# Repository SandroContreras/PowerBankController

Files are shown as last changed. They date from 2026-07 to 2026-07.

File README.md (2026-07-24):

# Power Bank Controller
Custom 8-cell lithium-ion power bank with embedded monitoring via MicroPython and OLED display.
<br><br>
**Project Status: PCB revision 1 ordered; assembly and electrical validation pending.**
<br><br>
## Overview
This project is a custom 8-cell (8×18650) lithium-ion power bank controller designed to explore
high-current PCB design, USB-C power delivery behavior, and real-world manufacturing constraints.
The board was designed in KiCad and fabricated as a 2-oz copper PCB.

<br>

## Features
- 8× LG MJ1 cells in parallel (~100.8 Wh)
- USB-C power output via IP5310 power-bank SoC
- 2 oz copper PCB for high-current paths
- Per-cell polyfuse protection
- Raspberry Pi Pico for battery monitoring
- Designed for serviceable, replaceable cells

<br>

## How It's Made
**Tech Used:** MicroPython, Raspberry Pi Pico, SSD1306 OLED Display
<br>
Eight 18650 batteries are wired in parallel to a boost converter charging module. The charging module powers the Pico Board and the OLED Display. To achieve battery health displays a voltage divider is used to safely bring down the voltage towards an ADC pin. The display is programmed to display the reported battery health percentage for the user. 

<br><br>

## Design Decisions & Tradeoffs
- Used 18650 holders instead of spot-welded packs to improve safety and serviceability.
- Selected 2 oz copper to reduce voltage drop and thermal stress in high-current paths.
- Chose IP5310 to simplify power-bank control while accepting uncertainty around USB-PD behavior.
- Accepted larger PCB size to prioritize current handling and mechanical robustness.

<br><br>

## Future Work
- Assemble and electrically validate the V1 prototype.
- Verify USB-C charging, 5 V boost output, OLED operation, and Raspberry Pi Pico functionality.
- Perform electrical and thermal testing under sustained load.
- Measure boost converter efficiency and battery runtime with the final 8-cell LG MJ1 battery pack.
- Design and fabricate a custom enclosure suitable for camping use.
- Evaluate the need for a V2 PCB revision based on functional and thermal test results.

<br><br>

## Data Flow

<p align="center">
    Data Flowchart
</p>
<p align="center"><em>Data flow from ADC voltage reading to OLED UI output.</em></p>

<br><br><br><br><br><br><br><br>

## Circuit Diagram

<p align = "center">
    Portable Power Bank - High-Level Circuit Diagram
</p>
<p align = "center"><em>High-Level Circuit Diagram.</em></p>

<p align = "center">
    Portable Power Bank - PCB Circuit Diagram
</p>
<p align = "center"><em>PCB Circuit Diagram.</em></p> 

<br><br><br>

## Lessons Learned
This project was my first complete custom PCB, from schematic capture through PCB layout, manufacturing, and assembly. Along the way I learned several practical engineering lessons:
    - The importance of verifying component footprints, pinouts, and manufacturer datasheets before ordering parts.
    - How PCB stack-up, copper pours, via placement, and trace widths affect power distribution and thermal performance.
    - The value of building a complete BOM and selecting components based on both electrical requirements and long-term serviceability.
    - That designing a functional hardware system often requires multiple design reviews and may require more than one PCB revision before reaching a mature design.

<br><br><br>

## Included Modules
- 'bisect.py' - From the Python Standard Library (CPython 3.13)
- Source: https://github.com/python/cpython
- License: Python Software Foundation License (PSF)

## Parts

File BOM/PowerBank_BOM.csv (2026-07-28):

BOM Revision: | V1 Prototype |  | Last Updated: | July 28, 2026
Item | Quantity Required | Quantity Stocked | Supplier | Datasheet | Unit Cost | Cost Per Board
PCB Manufacturing: | 5 | 0 |  |  | $93.31 | $145.12
PCB Shipping: | 1 | N/A |  |  | $59.05
Raspberry Pi Pico | 1 | 1 | Pi Pico Purchase | Pi Pico | $4.00
22uF Capacitor | 6 | 8 | 22uF Cap Purchase Link | 22uF Cap Datasheet | $0.95
1nF Capacitor | 1 | 10 | 1nF Cap Purchase Link | 1nF Cap Datasheet | $0.17
10uF Capacitor | 2 | 10 | 10uF Cap Purchase Link | 10uF Cap Datasheet | $0.43
1uF Capacitor | 1 | 0 | 1uF Cap Purchase Link | 1uF Cap Datasheet | $0.35
5.6V Zener Diode | 1 | 10 | 5.6V Zener Diode Purchase Link | Zener Datasheet | $0.56
Polyfuse | 8 | 0 | Polyfuse 2 Amp Hold Link | Polyfuse Datasheet | $0.60
USB-C Receptacle | 1 | 2 | USB-C Purchase Link | USB-C Port Datasheet | $0.61
Cell Holders | 8 | 8 | Cell Holder Link | Cell Holder Datasheet | $5.99
SDD1306 Oled | 1 | 3 | SSD1306 5 Pack Purchase Link | SSD1306 Oled Datasheet | $14.98
4 Pin Header Connector | 1 | 15 | Pin Header Purchase Link | Pin Header Datasheet | $0.69
1UH Inductor | 1 | 0 | 1UH Inductor Purchase Link | 1UH Inductor Datasheet | $1.97
PMOS Gate | 2 | 10 | PMOS Purchase Link | PMOS Datasheet | $0.50
BJT Gate | 1 | 10 | BJT Purchase Link | BJT Datasheet | $0.16
47k Resistor | 1 | 2 | 47k Resistor Purchase Link | 47k Resistor Datasheet | $0.27
100k Resistor | 2 | 2 | 100k Resistor Purchase Link | 100k Resistor Datasheet | $0.10
100k NTC THERM Resistor | 1 | 2 | 100k NTC THERM Resistor Purchase Link | 100k NTC THERM Datasheet | $0.51
1k Resistor | 1 | 25 | 1k Resistor Purchase Link | 1k Resistor Datasheet | $0.10
0 ohm Resistor | 1 | 2 | 0 ohm Resistor Purchase Link | 0 ohm Resistor Datsheet | $0.10
82k Resistor | 1 | 2 | 82k Resistor Purchase Link | 82k Resistor Datasheet | $0.10
10k Resistor | 3 | 25 | 10k Resistor Purchase Link | 10k Resistor Datasheet | $0.10
2 ohm Resistor | 1 | 2 | 2 ohm Resistor Purchase Link | 2 ohm Resistor Datasheet | $0.10
Button (TL6340AF160Q) | 1 | 0 | TL6340AF160Q Purchase Link | Button Datasheet | $0.45
PMIC (IP5310) | 1 | 5 | IP5310 Purchase Link | IP5310 Datasheet | $0.71
18650’s (LG MJ1) | 8 | 0 | 18650 Purchase Link |  | $5.00

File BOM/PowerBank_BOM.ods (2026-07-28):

BOM Revision: | V1 Prototype |  | Last Updated: | July 28, 2026
Item | Quantity Required | Quantity Stocked | Supplier | Datasheet | Unit Cost | Cost Per Board
PCB Manufacturing: | 5 | 0 |  |  | $93.31 | $145.12
PCB Shipping: | 1 | N/A |  |  | $59.05
Raspberry Pi Pico | 1 | 1 | Pi Pico Purchase (https://www.mouser.com/en/ProductDetail/Raspberry-Pi/SC0915?qs=T%252BzbugeAwjgnLi4azxXVFA%3D%3D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) | Pi Pico (https://datasheets.raspberrypi.com/pico/pico-datasheet.pdf) | $4.00
22uF Capacitor | 6 | 8 | 22uF Cap Purchase Link (https://www.mouser.com/en/ProductDetail/TAIYO-YUDEN/MCASE31LBB7226MTNA01?qs=FmjOKN4Os85Enbuat7%252BsuA%3D%3D) | 22uF Cap Datasheet (https://www.mouser.com/datasheet/3/940/1/c_mlcc_C_e.pdf) | $0.95
1nF Capacitor | 1 | 10 | 1nF Cap Purchase Link (https://www.digikey.com/en/products/detail/kemet/C1206C102K5RAC7210/3317018?gclsrc=aw.ds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) | 1nF Cap Datasheet (https://yageogroup.com/content/datasheet/asset/file/KEM_C1002_X7R_SMD) | $0.17
10uF Capacitor | 2 | 10 | 10uF Cap Purchase Link (https://www.digikey.com/en/products/detail/tdk/C3216X7R0J106K085AB/3952027?gclsrc=aw.ds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) | 10uF Cap Datasheet (https://product.tdk.com/system/files/dam/doc/product/capacitor/ceramic/mlcc/catalog/mlcc_commercial_general_en.pdf) | $0.43
1uF Capacitor | 1 | 0 | 1uF Cap Purchase Link (https://www.mouser.com/en/ProductDetail/KYOCERA-AVX/KAF31NR71C105JU?qs=Jm2GQyTW%2FbiSKYrUbBGHAg%3D%3D) | 1uF Cap Datasheet (https://www.mouser.com/datasheet/3/5926/1/AutoMLCCKAF.pdf) | $0.35
5.6V Zener Diode | 1 | 10 | 5.6V Zener Diode Purchase Link (https://www.digikey.com/en/products/detail/onsemi/1SMA5919BT3G/918093) | Zener Datasheet (https://www.onsemi.com/pdf/datasheet/1sma5913bt3-d.pdf) | $0.56
Polyfuse | 8 | 0 | Polyfuse 2 Amp Hold Link (https://www.mouser.com/en/ProductDetail/Littelfuse/1812L200THPR?qs=CPcc0c%2Fon9GqZ5cxSO73Dg%3D%3D) | Polyfuse Datasheet (https://www.littelfuse.com/assetdocs/resettable-ptcs-1812l-datasheet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) | $0.60
USB-C Receptacle | 1 | 2 | USB-C Purchase Link (https://www.digikey.com/en/products/detail/gct/USB4125-GF-A/13547388?gclsrc=aw.ds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) | USB-C Port Datasheet (https://gct.co/files/specs/usb4125-spec.pdf) | $0.61
Cell Holders | 8 | 8 | Cell Holder Link (https://www.digikey.com/en/products/detail/keystone-electronics/1042/2745668?gclsrc=aw.ds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) | Cell Holder Datasheet (https://www.keyelco.com/userAssets/file/K75p29.pdf) | $5.99
SDD1306 Oled | 1 | 3 | SSD1306 5 Pack Purchase Link (https://www.amazon.com/Hosyond-Display-Self-Luminous-Compatible-Raspberry/dp/B09C5K91H7) | SSD1306 Oled Datasheet (https://cdn-shop.adafruit.com/datasheets/SSD1306.pdf) | $14.98
4 Pin Header Connector | 1 | 15 | Pin Header Purchase Link (https://www.digikey.com/en/products/detail/3m/961104-6404-AR/7104635?gclsrc=aw.ds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) | Pin Header Datasheet (https://mm.digikey.com/Volume0/opasdata/d220001/medias/docus/587/961_2.54mm_StraightSolderTail_DS.pdf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..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) | $0.69
1UH Inductor | 1 | 0 | 1UH Inductor Purchase Link (https://www.mouser.com/en/ProductDetail/Murata-Electronics/LQH66SN1R0M03L?qs=0erBW18kMP5jh%2Ffsz3MtpA%3D%3D) | 1UH Inductor Datasheet (https://www.mouser.com/datasheet/3/76/2/JELF243A_0047.pdf) | $1.97
PMOS Gate | 2 | 10 | PMOS Purchase Link (https://www.digikey.com/en/products/detail/vishay-siliconix/SI2371EDS-T1-BE3/16397468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..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) | PMOS Datasheet (https://www.vishay.com/docs/63924/si2371eds.pdf) | $0.50
BJT Gate | 1 | 10 | BJT Purchase Link (https://www.digikey.com/en/products/detail/onsemi/BCW68GLT1G/1476121) | BJT Datasheet (https://www.onsemi.com/pdf/datasheet/bcw68glt1-d.pdf) | $0.16
47k Resistor | 1 | 2 | 47k Resistor Purchase Link (https://www.digikey.com/en/products/detail/vishay-dale/CRCW120647K0JNEAHP/2222486) | 47k Resistor Datasheet (https://www.vishay.com/docs/20043/crcwhpe3.pdf) | $0.27
100k Resistor | 2 | 2 | 100k Resistor Purchase Link (https://www.digikey.com/en/products/detail/stackpole-electronics-inc/RMCF1206FT100K/1759689) | 100k Resistor Datasheet (https://www.seielect.com/catalog/SEI-RMCF_RMCP.pdf) | $0.10
100k NTC THERM Resistor | 1 | 2 | 100k NTC THERM Resistor Purchase Link (https://www.digikey.com/en/products/detail/kyocera-avx/NB20N50104JBA/1451942) | 100k NTC THERM Datasheet (https://datasheets.kyocera-avx.com/nb21-nb12-nb20.pdf) | $0.51
1k Resistor | 1 | 25 | 1k Resistor Purchase Link (https://www.digikey.com/en/products/detail/yageo/RC1206FR-131KL/13694125?gclsrc=aw.ds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) | 1k Resistor Datasheet (https://yageogroup.com/content/datasheet/asset/file/PYU-RC_GROUP_51_ROHS_L) | $0.10
0 ohm Resistor | 1 | 2 | 0 ohm Resistor Purchase Link (https://www.digikey.com/en/products/detail/yageo/RC1206FR-130RL/16982181?gclsrc=aw.ds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) | 0 ohm Resistor Datsheet (https://yageogroup.com/content/datasheet/asset/file/PYU-RC_GROUP_51_ROHS_L) | $0.10
82k Resistor | 1 | 2 | 82k Resistor Purchase Link (https://www.digikey.com/en/products/detail/yageo/RC0603FR-1082KL/14286523?gclsrc=aw.ds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) | 82k Resistor Datasheet (https://yageogroup.com/content/datasheet/asset/file/PYU-RC_GROUP_51_ROHS_L) | $0.10
10k Resistor | 3 | 25 | 10k Resistor Purchase Link (https://www.digikey.com/en/products/detail/yageo/RC1206FR-1010KL/13694170?gclsrc=aw.ds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) | 10k Resistor Datasheet (https://yageogroup.com/content/datasheet/asset/file/PYU-RC_GROUP_51_ROHS_L) | $0.10
2 ohm Resistor | 1 | 2 | 2 ohm Resistor Purchase Link (https://www.digikey.com/en/products/detail/yageo/RT1206DRE072RL/7708680) | 2 ohm Resistor Datasheet (https://yageogroup.com/content/datasheet/asset/file/PYU-RT_1-TO-0-01_ROHS_L) | $0.10
Button (TL6340AF160Q) | 1 | 0 | TL6340AF160Q Purchase Link (https://www.digikey.com/en/products/detail/e-switch/TL6340AF160Q/11684842) | Button Datasheet (https://configured-product-images.s3.amazonaws.com/Datasheets/TL6340.pdf) | $0.45
PMIC (IP5310) | 1 | 5 | IP5310 Purchase Link (https://www.lcsc.com/product-detail/Others_INJOINIC-IP5310_C191176.html) | IP5310 Datasheet (http://www.sztuofeng.com/upload/1586855153.pdf) | $0.71
18650’s (LG MJ1) | 8 | 0 | 18650 Purchase Link (https://18650battery.com/products/lg-mj1-18650-3500mah-10a-battery?variant=48703038456118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) |  | $5.00

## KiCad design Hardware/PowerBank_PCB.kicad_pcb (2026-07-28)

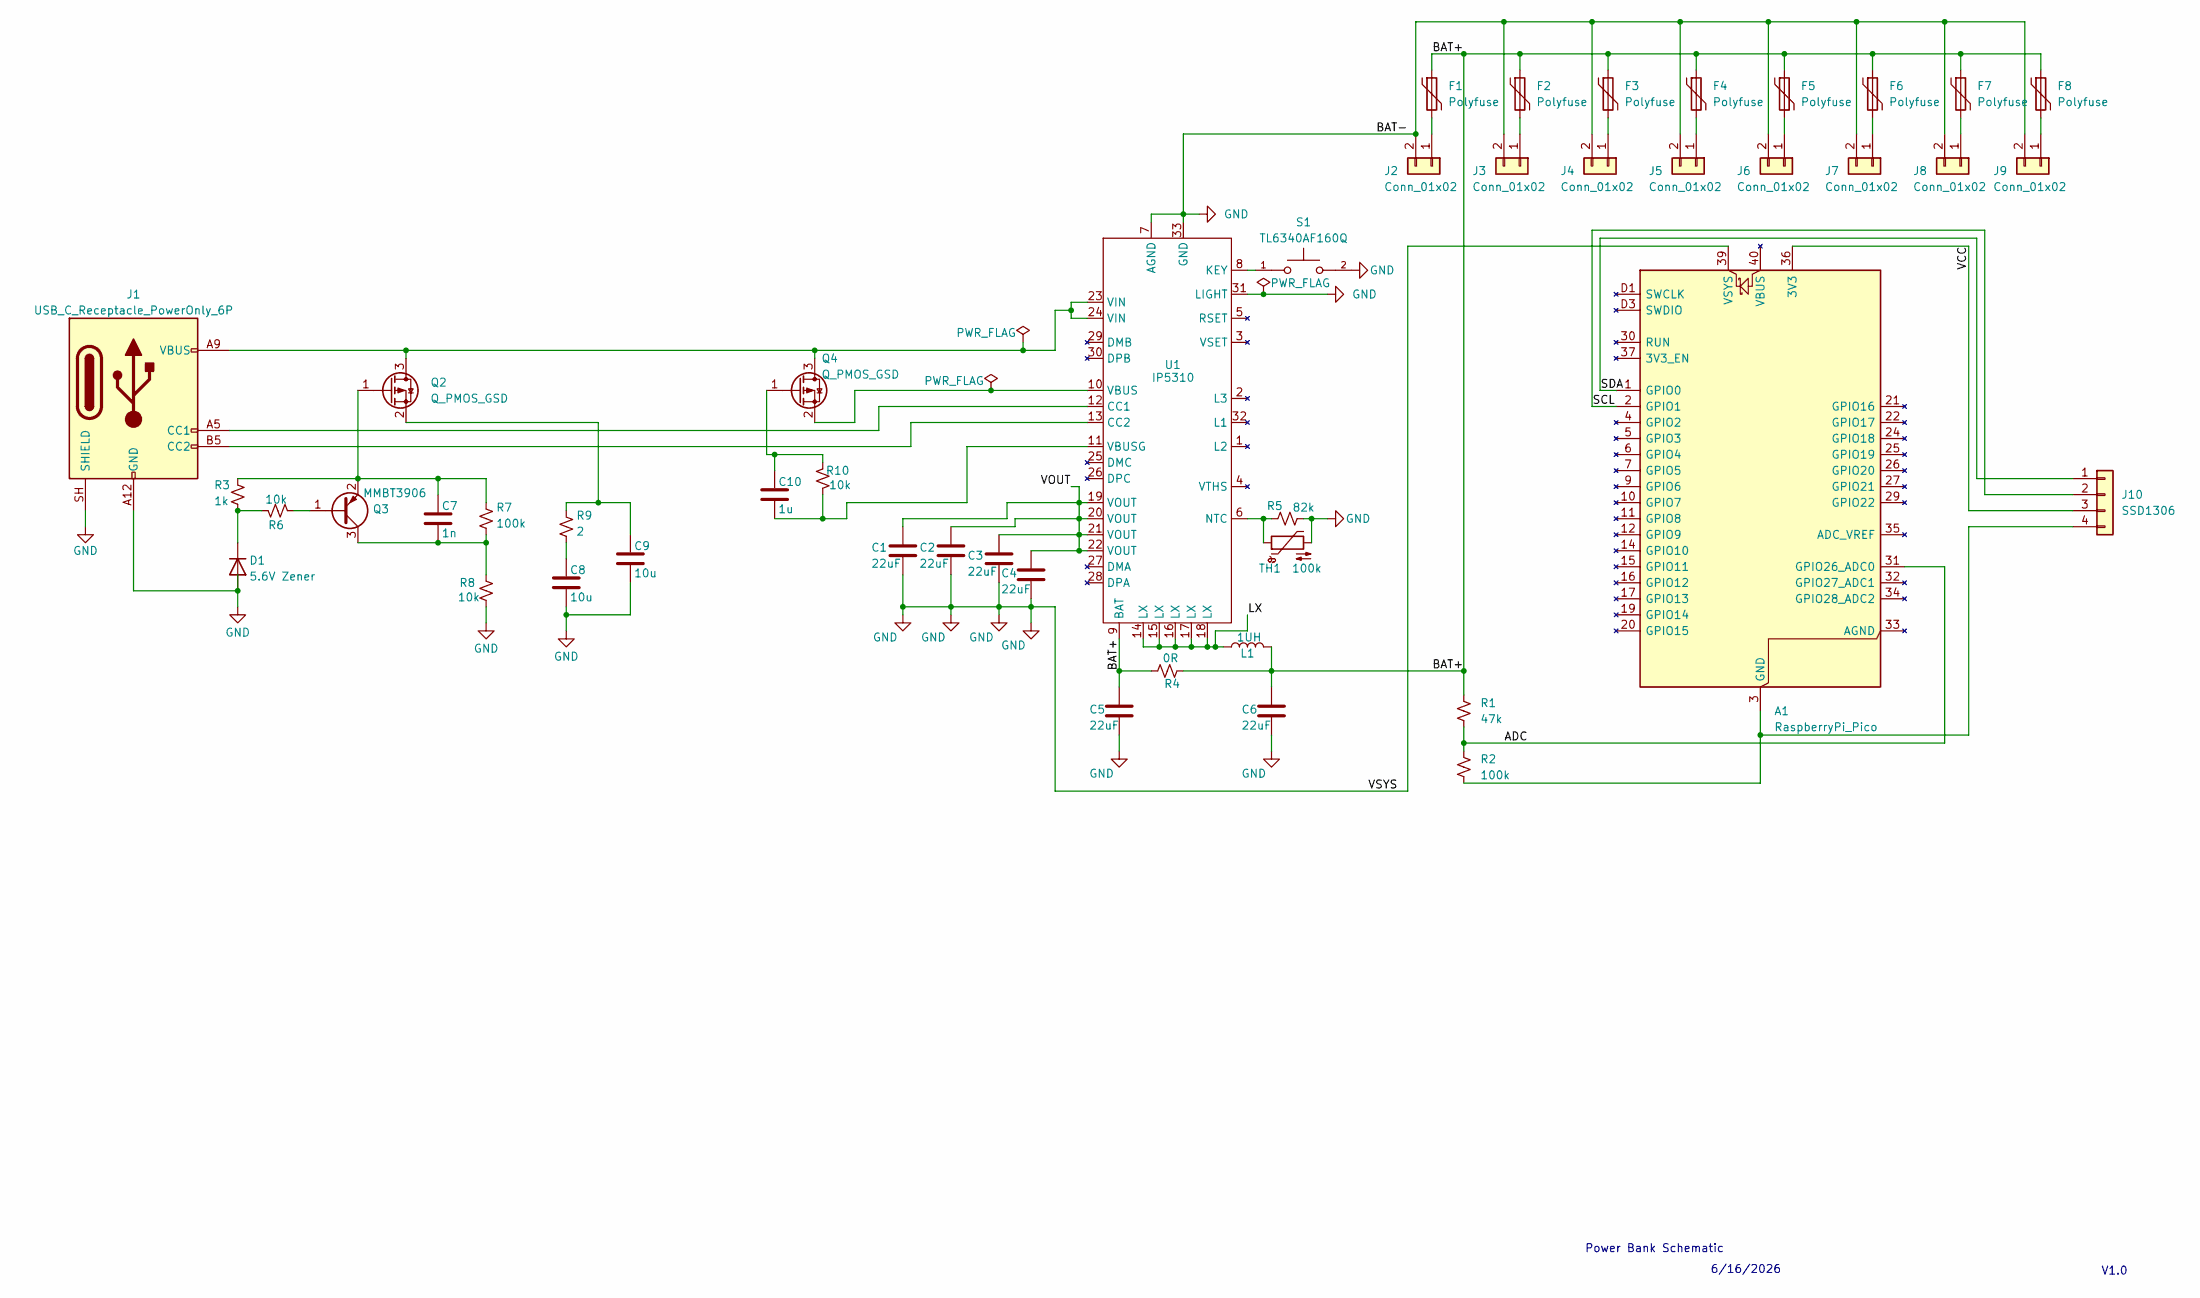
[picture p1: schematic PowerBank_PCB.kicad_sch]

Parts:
A1: RaspberryPi_Pico; RaspberryPi_Pico_SMD_HandSolder
C1, C2, C3, C4, C5, C6: 22uF; C_1206_3216Metric_Pad1.33x1.80mm_HandSolder
C7: 1n; C_1206_3216Metric_Pad1.33x1.80mm_HandSolder
C8, C9: 10u; C_1206_3216Metric_Pad1.33x1.80mm_HandSolder
C10: 1u; C_1206_3216Metric_Pad1.33x1.80mm_HandSolder
D1: 5.6V Zener; D_SMA_Handsoldering
F1, F2, F3, F4, F5, F6, F7, F8: Polyfuse; Fuse_1812_4532Metric_Pad1.30x3.40mm_HandSolder
J1: USB_C_Receptacle_PowerOnly_6P; USB_C_Receptacle_GCT_USB4125-xx-x_6P_TopMnt_Horizontal
J2, J3, J4, J5, J6, J7, J8, J9: Conn_01x02; BatteryHolder_Keystone_1042_1x18650
J10: SSD1306; PinHeader_1x04_P2.54mm_Vertical
L1: 1UH; L_6.3x6.3_H3
Q2, Q4: Q_PMOS_GSD; SOT-23_Handsoldering
Q3: MMBT3906; SOT-23_Handsoldering
R1: 47k; R_1206_3216Metric_Pad1.30x1.75mm_HandSolder
R2, R7: 100k; R_1206_3216Metric_Pad1.30x1.75mm_HandSolder
R3: 1k; R_1206_3216Metric_Pad1.30x1.75mm_HandSolder
R4: 0R; R_1206_3216Metric_Pad1.30x1.75mm_HandSolder
R5: 82k; R_1206_3216Metric_Pad1.30x1.75mm_HandSolder
R6, R8, R10: 10k; R_1206_3216Metric_Pad1.30x1.75mm_HandSolder
R9: 2; R_1206_3216Metric_Pad1.30x1.75mm_HandSolder
S1: TL6340AF160Q; SW_TL6340AF160Q; PARTREV 10.23.2019
TH1: 100k; R_1206_3216Metric_Pad1.30x1.75mm_HandSolder
U1: IP5310; QFN-32-1EP_5x5mm_P0.5mm_EP3.3x3.3mm_ThermalVias

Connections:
/ADC: A1.31 (GPIO26_ADC0), R1.2, R2.1
/BAT+: C5.1, C6.1, F1.1, F2.1, F3.1, F4.1, F5.1, F6.1, F7.1, F8.1, L1.2, R1.1, R4.1, R4.2, U1.9 (BAT)
/LX: L1.1, U1.14 (LX), U1.15 (LX), U1.16 (LX), U1.17 (LX), U1.18 (LX)
/SCL: A1.2 (GPIO1), J10.2 (SCL)
/SDA: A1.1 (GPIO0), J10.1 (SDA)
/VCC: A1.36 (3V3), J10.3 (VCC)
/VOUT: C1.1, C2.1, C3.1, C4.1, U1.19 (VOUT), U1.20 (VOUT), U1.21 (VOUT), U1.22 (VOUT)
GND: A1.39 (VSYS), C1.2, C2.2, C3.2, C4.2, C5.2, C6.2, C8.2, C9.2, D1.2 (A), J1.A12 (GND), J1.B12 (GND), J1.SH (SHIELD), J2.2, J3.2, J4.2, J5.2, J6.2, J7.2, J8.2, J9.2, R5.2, R8.2, S1.2, TH1.2, U1.7 (AGND), U1.31 (LIGHT), U1.33 (GND)
unnamed: C8.1, R9.2
unnamed: D1.1 (K), R3.2, R6.1
unnamed: J1.A5 (CC1), U1.12 (CC1)
unnamed: J1.B5 (CC2), U1.13 (CC2)
unnamed: F1.2, J2.1
unnamed: F2.2, J3.1
unnamed: F3.2, J4.1
unnamed: F4.2, J5.1
unnamed: F5.2, J6.1
unnamed: F6.2, J7.1
unnamed: F7.2, J8.1
unnamed: F8.2, J9.1
unnamed: A1.3 (GND), A1.8 (GND), A1.13 (GND), A1.18 (GND), A1.23 (GND), A1.28 (GND), A1.38 (GND), A1.D2 (GND), J10.4 (GND), R2.2
unnamed: J1.A9 (VBUS), J1.B9 (VBUS), Q2.3 (D), Q4.3 (D), U1.23 (VIN), U1.24 (VIN)
unnamed: C7.1, Q2.1 (G), Q3.2 (E), R3.1, R7.1
unnamed: C9.1, Q2.2 (S), R9.1
unnamed: Q3.1 (B), R6.2
unnamed: C7.2, Q3.3 (C), R7.2, R8.1
unnamed: C10.1, Q4.1 (G), R10.1
unnamed: Q4.2 (S), U1.10 (VBUS)
unnamed: S1.1, U1.8 (KEY)
unnamed: R5.1, TH1.1, U1.6 (NTC)
unnamed: C10.2, R10.2, U1.11 (VBUSG)

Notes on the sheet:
6/16/2026
V1.0
Power Bank Schematic

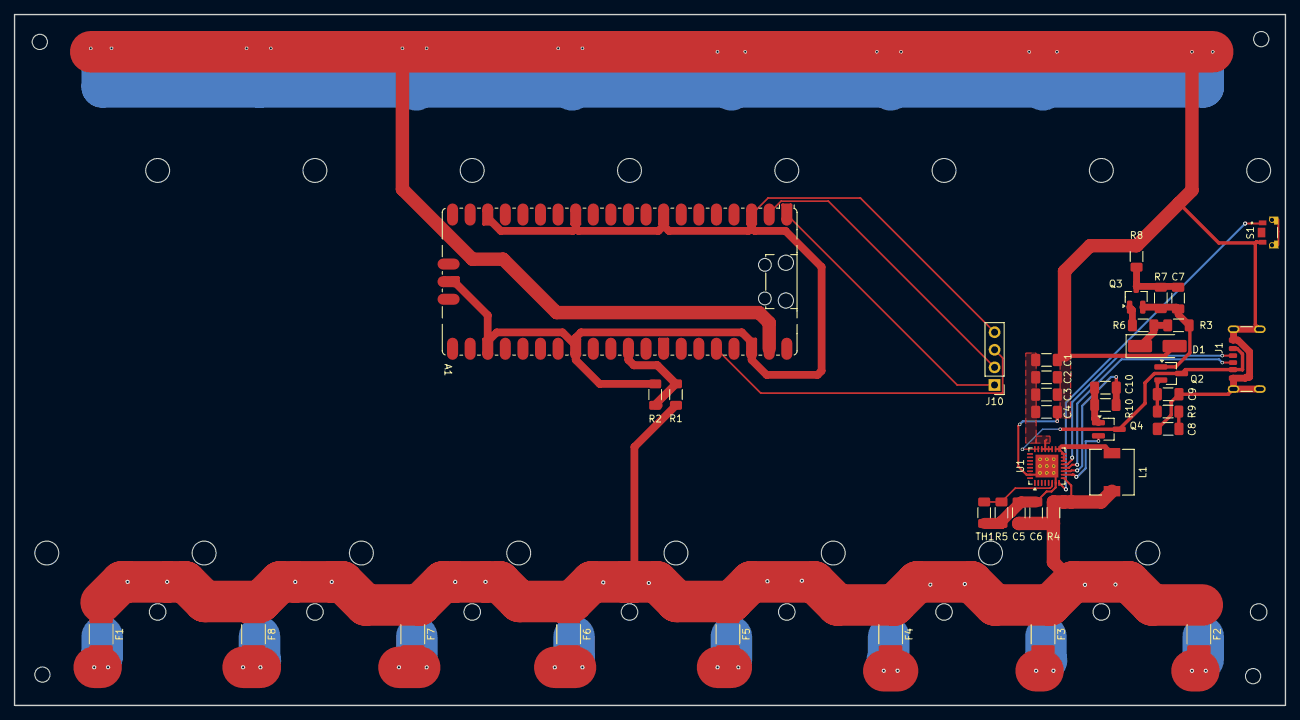
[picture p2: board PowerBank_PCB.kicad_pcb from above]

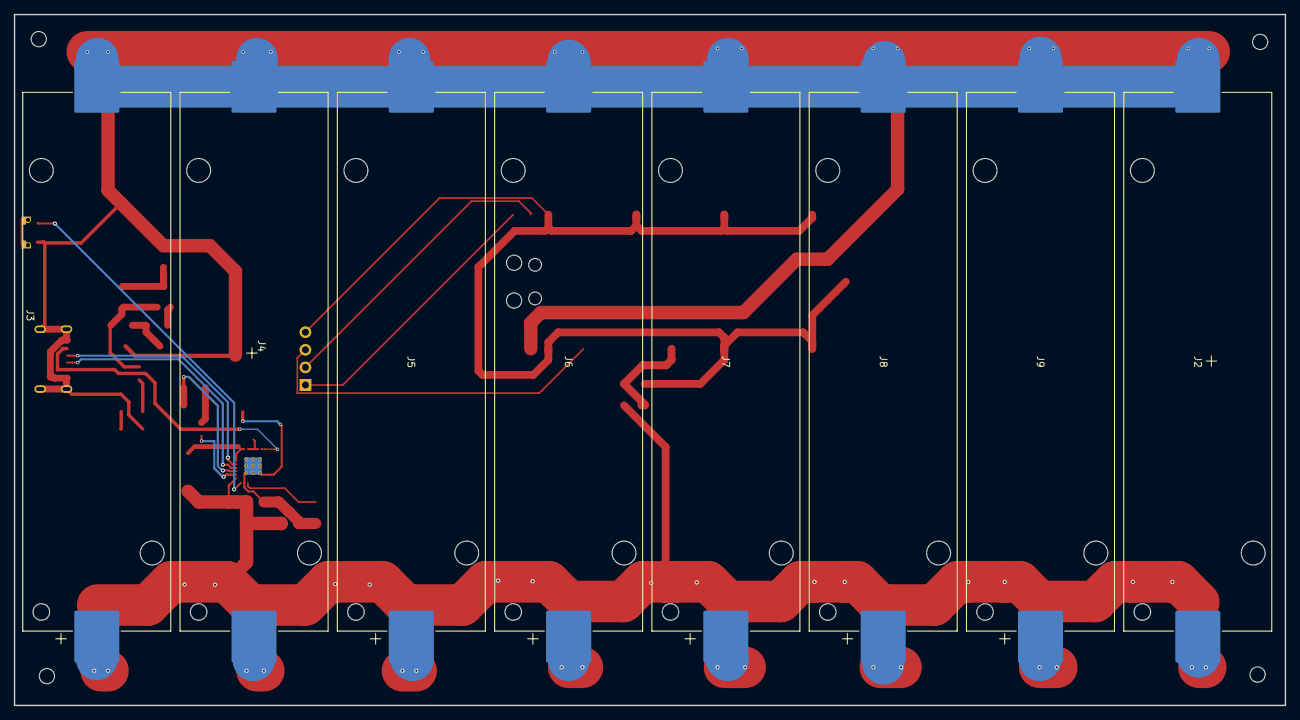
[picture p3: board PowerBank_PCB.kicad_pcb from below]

Board: 4 copper layers, 183.5 x 99.8 mm, 47 parts (8 on the bottom side), 31 nets.

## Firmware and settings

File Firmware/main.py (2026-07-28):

from machine import Pin, I2C
import ssd1306
import time
import bisect
from machine import ADC
from PowerBank import BatteryManager, OledUI
## main.py
## Author: Sandro Contreras II
## License: MIT
## Description: Monitors battery voltage and displays battery health
##				using an OlED screen through modular method calls.
## Notes:
## - Named file "main.py" to follow MicroPython auto-run feature
## - This library (ssd1306.py) was manually downloaded from:
##   https://gist.github.com/cwyark/d7f2becd84b0b69b05a83315bf84c467
##   Not included in repo due to license uncertainty.
time.sleep(0.3)		## Allow for Boot time

# Initialize I2C
i2c = I2C(0, scl=Pin(1), sda=Pin(0))

# Create display object (128x64 OLED at address 0x3C)
oled = ssd1306.SSD1306_I2C(128, 64, i2c)

## Create ADC object on an ADC pin
adc = ADC(Pin(26))	## GPIO 26 on Pico is an ADC0 Pin

battery_percent_str = ""
previous_battery_percent_str = ""
previous_battery_percentage = 0

BatteryMethods = BatteryManager(adc)
OledMethods = OledUI(oled)

while True:
    
    previous_battery_voltage = BatteryMethods.PowerCalculator()
    
    time.sleep_ms(200)		# Add a delay between readings for comparison

    BatteryMethods.PowerCalculator()

    BatteryMethods.SetWindowSize()

    BatteryMethods.BatteryVoltage_SMA()		## Use SMA to smoothen out the battery percentage
    
    battery_percentage = BatteryMethods.SOCtable(previous_battery_percent_str, battery_percent_str)							## battery_percentage is an integer

    battery_percent_str = str(battery_percentage)
    
    BatteryMethods.Check_movingAvgArr()
    
    OledMethods.OledSignal(BatteryMethods, previous_battery_percentage, battery_percent_str)
    
    previous_SMA_battery_voltage = OledMethods.BatteryVoltageUpdater(BatteryMethods)	# Update the lower bounds to avoid an always on state
    
    previous_battery_percentage = battery_percentage

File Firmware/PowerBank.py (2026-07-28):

## PowerBank.py
## Author: Sandro Contreras II
## License: MIT
## Description: This file contains the PowerBank class, which handles battery monitoring
##				and OLED display logic.
## Notes:
## - Includes modular methods for power evaluation using voltage divider math
##	 and a Simple Moving Average (SMA) for smoothing. 
## - Designed to be utilized by main.py as a backend.
from machine import Pin, I2C
import ssd1306
import bisect
import time
from machine import ADC

class BatteryManager:
    def __init__(self, adc):
        self.adc = adc
        self.raw = 0
        self.adc_voltage = 0
        self.movingAvg = []
        self.windowSize = 0
        self.SMA_battery_voltage = 0
        self.BatteryVoltageArr = []
        self.battery_voltage = 0
        self.battery_percentage = 0
    
    def PowerCalculator(self):						## Values 0 - 65535 represents voltages between 0V - 3.3V
        self.raw = self.adc.read_u16()					## Read a Raw analog value in the range 0 - 65535
        self.adc_voltage = (self.raw * 3.3 / 65535)		## Find Adc Voltage
        ## R1 = 47k ohm, R2 = 100k ohm
        self.battery_voltage = self.adc_voltage * 1.47 	## Battery Voltage = Adc Voltage * ((R1+R2) / R2)
    
    def SetWindowSize(self):		## Lithium batteries don't charge linearly
        if self.battery_voltage < 3.7:
            self.windowSize = 30
        elif self.battery_voltage < 3.9:
            self.windowSize = 20
        elif self.battery_voltage < 4.01:
            self.windowSize = 15
        elif self.battery_voltage < 4.05:
            self.windowSize = 8
        elif self.battery_voltage >= 4.05 and self.battery_voltage < 4.061:
            self.windowSize = 8
        elif self.battery_voltage >= 4.061:
            self.windowSize = 5
    
    def BatteryVoltage_SMA(self):

        if (len(self.BatteryVoltageArr) < self.windowSize):
            self.BatteryVoltageArr.append(self.battery_voltage)
        elif len(self.BatteryVoltageArr) == self.windowSize:		## If length of moving data meets the Window Size, then perform SMA
            self.BatteryVoltageArr.pop(0)
            self.BatteryVoltageArr.append(self.battery_voltage)
            self.SMA_battery_voltage = (sum(self.BatteryVoltageArr) / len(self.BatteryVoltageArr))
            
            if (len(self.movingAvg) < 60):	## Handle previous memory crash by limiting Moving Average Array size
                self.movingAvg.append(self.SMA_battery_voltage)
            else:
                self.movingAvg.pop(0)
    
    def SOCtable(self, previous_battery_percent_str, battery_percent_str):
        VoltageRange = [2.8, 3.0, 3.1, 3.2, 3.3, 3.35, 3.4, 3.45, 3.50, 3.55, 3.6, 3.7, 3.75, 3.8, 3.9, 3.95, 4.0, 4.03, 4.05, 4.06, 4.07, 4.08]
        Percentage =   [  2,   5,   7,  10,  13,   15,  20,   25,   30,   35,  40,  50,   60,  65,  70,   75,  80,   85,   90,   95,   98,  100]
        print("SMA in SOC = " + str(self.SMA_battery_voltage))
        
        if (self.SMA_battery_voltage < 2.8):
            Index = 0
        elif (self.SMA_battery_voltage > 4.08) :
            Index = len(VoltageRange) - 1
        else:
            Index =  bisect.bisect_right(VoltageRange, self.SMA_battery_voltage) - 1
            
#         if (previous_battery_percent_str != "" and battery_percent_str != ""):
#             return self.sticky(previous_battery_percent_str, battery_percent_str)
#         else:
#             return Percentage[Index]
            
        return Percentage[Index]
        
    def Check_movingAvgArr(self):
        if (len(self.movingAvg) >= 1):
            return True
        else: return False
    
#     def sticky(self, previous_battery_percent_str, battery_percent_str):
#         flag = any(voltage == 4.06 for voltage in self.movingAvg)
#         
#         if (flag):
#             if (int(previous_battery_percent_str) >= 95 and Percentage[Index] < int(previous_battery_percent_str)):
#                 return previous_battery_percent_str
#             elif (int(previous_battery_percent_str) >= 95 and Percentage[Index] > int(previous_battery_percent_str)):
#                 return Percentage[Index]
#         else:
#             return Percentage[Index]
            
class OledUI():
    def __init__(self, oled):
        
        self.previous_SMA_battery_voltage = 0
        self.oled = oled
        self.percentSymbol = "%"
        
    def BatteryVoltageUpdater(self, BatteryMethods):
        self.previous_SMA_battery_voltage = BatteryMethods.SMA_battery_voltage
        return self.previous_SMA_battery_voltage
        
    def DrawBatteryPercentage(self, BatteryMethods, battery_percent_str):
        
        if (BatteryMethods.SMA_battery_voltage < 3.2):	## Shift Percent Symbol inwards towards the Single Digit Value
            self.oled.text(self.percentSymbol, 65, 2)
            self.oled.text(battery_percent_str, 57, 2)
        elif (BatteryMethods.SMA_battery_voltage < 4.08):	## Display Battery Percentage for Double Digit Value
            self.oled.text(self.percentSymbol, 65, 2)
            self.oled.text(battery_percent_str, 50, 2)
        elif (BatteryMethods.SMA_battery_voltage < 4.09 or BatteryMethods.SMA_battery_voltage > 4.09):	## Triple digit value display
            self.oled.text(self.percentSymbol, 75, 2)
            self.oled.text(battery_percent_str, 50, 2)
        
    def DrawChargingSymbol(self, BatteryMethods):
        
        VoltageChangeRate = BatteryMethods.SMA_battery_voltage - self.previous_SMA_battery_voltage
        
        if (VoltageChangeRate > 0.0003 and self.previous_SMA_battery_voltage != 0):		## The Charging symbol will only appear if the Bank is Charging
            if (BatteryMethods.SMA_battery_voltage < 4.07):
                ## Create Charging Symbol
                self.oled.vline(85, 0, 16, 1)
                self.oled.hline(85, 6, 8, 1)	## Create horizontal line at halfway point at charging symbol
                self.oled.hline(78, 9, 8, 1)	## Create horizontal line at halfway point at charging symbol

                ## Inner Symbol Fillings
                self.oled.fill_rect(82, 6, 5, 4, 1)
                self.oled.fill_rect(85, 6, 4, 4, 1)
                self.oled.fill_rect(83, 2, 2, 4, 1)
                self.oled.fill_rect(79, 7, 12, 2, 1)
                self.oled.fill_rect(85, 8, 4, 4, 1)
                self.oled.fill_rect(89, 9, 1, 1, 1)
                self.oled.fill_rect(86, 12, 1, 3, 1)
                self.oled.fill_rect(81, 4, 3, 3, 1)
            
            else:
                ## Create Charging Symbol
                self.oled.vline(93, 0, 16, 1)
                self.oled.hline(93, 6, 8, 1)	## Create horizontal line at halfway point at charging symbol
                self.oled.hline(86, 9, 8, 1)	## Create horizontal line at halfway point at charging symbol
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

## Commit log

2025-06-15 Updated Battery Status Check
    Due to a lack of Fuel Gauge Chips, now we are using SOC to determine the Battery Health
2025-06-15 Updated Resistor Values
    The resistors used were properly updated in the Battery Voltage math
2025-06-15 Update main.py Resistor value again
2025-06-16 Implemented SMA for Voltages
    Added SMA to reduce noise in Battery Voltage Calculations, for use in the SOC table
    [main.py]
2025-06-16 Transformed Code into Functions
    I took loose code and created functions to clean up the While Loop sequence.
    [main.py]
2025-06-22 Optimized SMA function and Added Battery Symbol
    Reworked the SMA function, and a Battery Symbol drawing was pushed to the OLED. The "Battery:" text display was removed from the Display. The Battery Symbol will be on the upper left, alongside the battery health percentage on the right. Next, a conditional charging symbol will be added next to the battery drawing.
    [main.py]
2025-06-25 Implemented New Logic Display Rules
    Added new logic for shifting the Percentage % Symbol depending on whether the battery health is single-digit or double-digit. Added Logic to display the Charging Symbol ONLY when the Power Bank is Charging. Next, I will move the current battery voltage reading into the while loop to avoid a constant comparison value.
    [main.py]
2025-06-25 Fixed SMA function
    Fixed the SMA value append bug and moved the return value outside the while loop.
    [main.py]
2025-06-25 Fixed Value Loss Bug
    Now we are using variable battery_voltage to capture the result of the Battery Voltage SMA function to capture the latest SMA value.
    [main.py]
2025-06-25 Removed Global Variable
    Replaced the Global battery_voltage variable by passing the battery_voltage variable to the BatteryVoltage_SMA() function.
    [main.py]
2025-06-28 Refactored Code (Moved into a Function)
    I moved the power reading code into a PowerCalculator() function. I moved the previous_battery_voltage code into the while loop, which uses the new function. I added an if-elif statement structure th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
2025-06-28 Added Battery Symbol Fillings
    I added the necessary drawings needed to fill the battery symbol quadrants when the battery voltage conditionals are met.
2025-06-30 Refactor: converted codebase to OOP design
    All functions were moved into classes, and methods were created. The code will be tested shortly. The code base is now in OOP form.
    [main.py]
2025-06-30 Fixed Syntax Errors
    Syntax Errors are now cleared. Next, I will ensure the program functions again with classes now.
    [main.py]
2025-06-30 Program Functions
    The Program appears to function within the IDE. There are no more errors. I started the parallel list for the voltage and percentage comparisons.
    [main.py]
2025-07-14 Created PowerBank.py Class File
    I created the PowerBank.py Class file which now contains all previous classes from main.py. The program is buggy currently, fixes are coming soon.
    [PowerBank.py, main.py]
2025-07-15 Voltage Readings Function
    Raw voltage data is flowing through the output terminal. Next, debug the array of voltages.
2025-07-16 Rearranged UI Symbols
    I moved the battery percentage value and symbol next to the battery symbol on the left. The charging symbol will now flash on the right side of the battery health percentage symbol.
2025-07-25 Increased SMA Window & Added new Variables
    I increased the SMA window from 12 to 60 to smooth out the battery voltages. I added new variables, time & updated_time to eventually use the time method to implement a throttler for the OLED display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
2025-07-30 Implemented SetWindowSize() method
    Created SetWindowSize(battery_voltage) method to adjust SMA Window Size according to 18650's non-linear voltage curve. When the 18650s have less than 3.9 V present, noise is greater, so a larger window size is implemented. Beyond 3.9 V, lithium batteries experience incremental voltage gains, and a smaller SMA Window Size is in place.
    [PowerBank.py, main.py]
2025-07-31 Functions w/o Errors, Incomplete Logic
    Code Functions, but Logic needs to be completed, and the program must be stabilized.
    [PowerBank.py]
2025-08-02 Modularized OledSignal() method
    I modularized the OledSignal() method by transferring its contents into modular method calls. New methods established: DrawBatteryPercentage(battery_voltage, percentSymbol, battery_percent_str), Draw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
2025-08-02 Update PowerBank.py
    Credited the library SSD1306
2025-08-08 Organize project files: New directories
    Added code/ and images/ directories for python scripts and data flow charts to be stored.
2025-08-08 Added Data Flowchart to README.md
2025-08-10 Fixed Array Sharing Issue / Added WindowSize Check
    Now the BatteryVoltageArr is shared across both classes correctly. A window size checker was implemented to display a boot message until the window size is met. Now I must stabilize the power stagnation check by implementing time stamp checks for power stagnations.
    [PowerBank.py, main.py]
2025-08-13 Improved SMA method / Debugged Program
    Revamped SMA method with new implementation. Improved code stability by utilizing SMA_battery_voltage instead of the raw battery_voltage input throughout display logic. Now SMA method uses raw voltage input only, instead of feeding back SMA results into the SMA method. Now the SMA method returns SMA_battery_voltage instead of battery_voltage.
    [PowerBank.py, main.py]
2025-08-14 Circuit Diagram Added
2025-08-14 Portable Power Bank Diagram Tweaks
2025-08-16 Update PowerBank.py
    removed unnecessary comment
2025-08-18 Fixed SMA Bug / Improved Boot time
    SMA function was fixed by implemnting the appending of a new value within the second boolean condition of the SMA method. Boot time was improved significantly by reducing sleep time from 5 seconds to 4 miliseconds in main.py
    [PowerBank.py, main.py]
2025-08-18 Update PowerBank.py
    removed extra Array.pop(0) inside of SMA function
2025-08-18 Code is fairly stable, just need to implment idle logic
    main function is stable aside from unstable idle power bank logic.
    [PowerBank.py, main.py]
2025-12-29 Improved Battery Symbol UI & Refactored Boot Logic to SMA Dependency
    Improved Battery Symbol UI through incrementing the rectangle widths as needed. Now the boot logic depends on a boolean tracking if SMA occurred. This switch enables functional use of OLED during mod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
2025-12-30 Corrected Use of self. objects in codebase
    Simplified codebase through correcting improper usage of self. throughout the codebase. Now all elements utilize the objects.
    [PowerBank.py, main.py]
2025-12-30 Scaled down SOC table
    Scaled down SOC table voltage elements beyond 3.95 V. Testing revealed system voltage ceiling to be 4.07V. Scaled down to accurately display battery life percentage.
2026-01-19 Added PCB Schematic
    This is the low-level schematic of our PCB.
2026-01-20 Updating PCB Schematic Image
2026-01-20 Updating High-Level Schematic image
2026-01-20 Added PCB files
    [PowerBank_PCB.kicad_pcb, PowerBank_PCB.kicad_sch]
2026-06-14 Implemented proper Circuit for USB-C Input/Output
    Implemented PMOS transistors to provide USB-C Input/Output functionalities
    [PowerBank_PCB.kicad_sch]
2026-06-17 Added Correct Footprints
    The Schematic is now completed with the correct Foot Prints
    [PowerBank_PCB.kicad_pcb, PowerBank_PCB.kicad_sch]
2026-07-24 Updated Schematic
2026-07-28 Reorganize project folders and added BOM
    [PowerBank_BOM.ods, PowerBank_PCB.kicad_pcb, PowerBank_PCB.kicad_sch]
2026-07-28 Added .csv BOM file
    [PowerBank_BOM.csv, PowerBank_BOM.ods, PowerBank_PCB.kicad_pcb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]
